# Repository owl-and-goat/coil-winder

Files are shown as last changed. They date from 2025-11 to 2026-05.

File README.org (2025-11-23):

#+title: coil winder

this repository contains the source for a mostly 3d-printed, gcode controlled,
wifi-connected cnc coil winder, including the [[https://github.com/owl-and-goat/coil-winder/tree/main/firmware][firmware]], a [[https://github.com/owl-and-goat/coil-winder/tree/main/client][client]] for controlling
it from a computer, a simple [[https://github.com/owl-and-goat/coil-winder/tree/main/slicer]["slicer" program]] for generating gcode to wind
various sorts of electromagnetic coils, and the [[https://github.com/owl-and-goat/coil-winder/tree/main/parts][STL files]] for the 3D-printed parts

the whole thing is driven off of a single [[https://www.raspberrypi.com/products/raspberry-pi-pico/][pi pico w]] microcontroller, with four
[[https://www.adafruit.com/product/6109][a4988 stepper driver]] boards for controlling the stepper motors.

coming soon: a longer writeup of how everything works, including instructions on
how to build one yourself if you want

* photos

here's how it looks in cad:

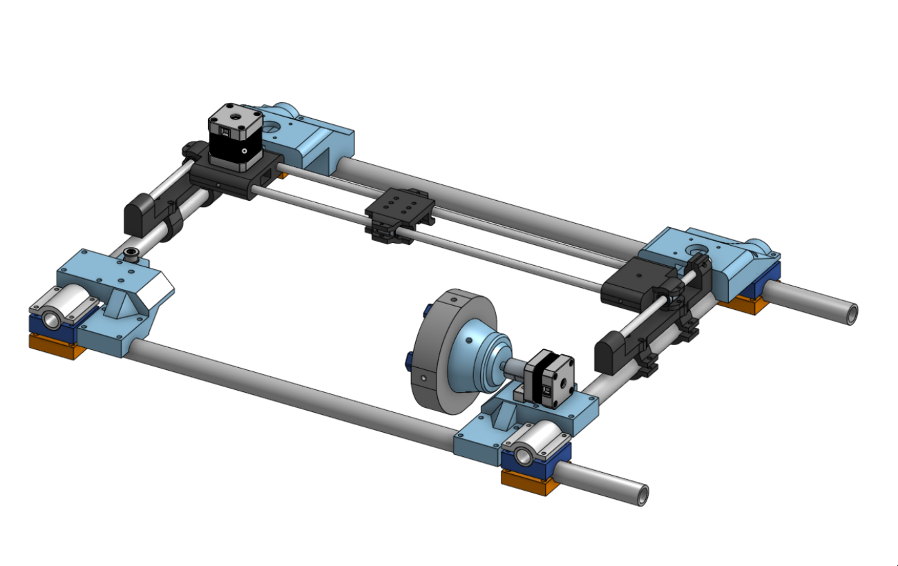
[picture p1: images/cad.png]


and here's how it looks in real life:

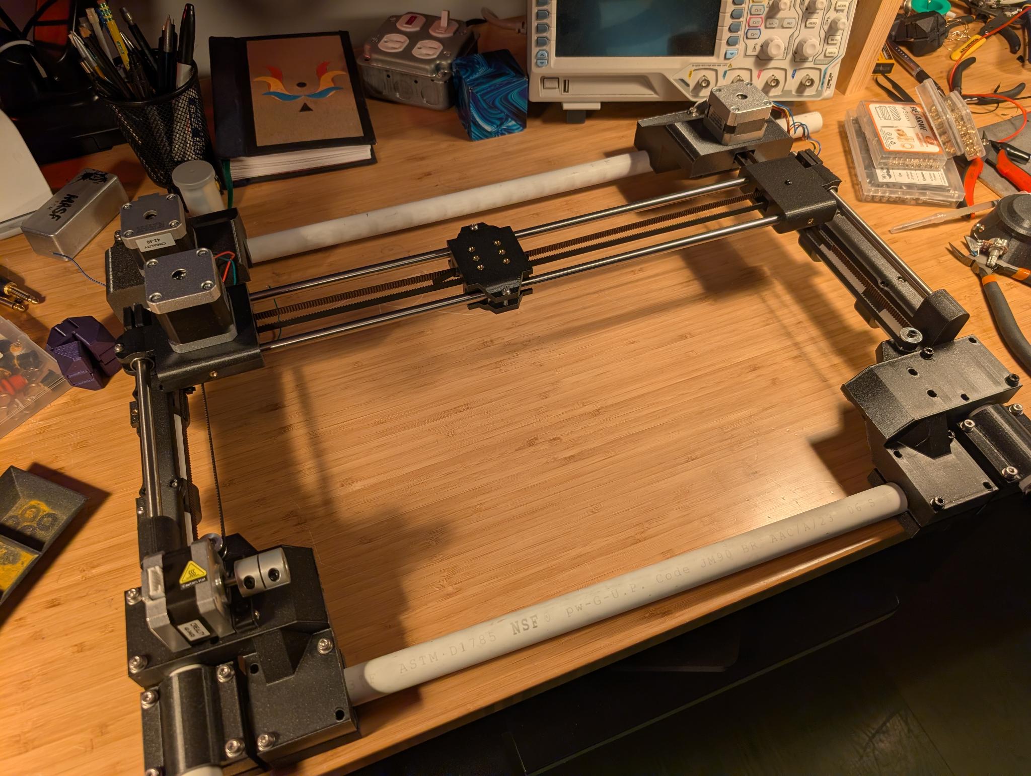
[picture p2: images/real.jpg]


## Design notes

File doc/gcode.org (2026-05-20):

#+TITLE: Supported GCode commands

We've been using https://reprap.org/wiki/G-code for inspiration.

+ *G0 X<x> Z<z> C<c> F<f>* - Rapid move
  All coordinates optional

  *F* is feedrate, in millimeters per second

+ *G1 X<x> Z<z> C<c> F<f>* - Linear move
  All coordinates optional

  *F* is feedrate, in millimeters per second

  G0 and G1 are synonyms for now

+ *G4 <dur>* - Dwell (sleep)

+ *G28 [F<speed>]* - Home

  *F* is optional feedrate, in millimeters per second. Defaults to 120

+ *M0* - Stop

+ *M17* - Enable all steppers

+ *M18* - Disable all steppers

+ *M112* - Force stop (resets processor)

+ *M114* - Get current position

  Prints current position to debug console

+ *M226* - Pause

  Pause until the "Resume" button is pressed

* Standard preamble

#+begin_src gcode
M0
M17
G28
#+end_src

* Standard postamble

#+begin_src gcode
M18
#+end_src

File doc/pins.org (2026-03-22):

#+title: Pins

* Axes

In order:
- *X* - diameter axis. two motors
- *Z* - axis parallel to the spindle. one motor
- *C* - spindle

** Pins

#+attr_org: :width 1000
[[file:./pico-2-r4-pinout.svg]]

all directions (left, right, ...) are given wrt. the pico in the above
orientation.

- sleep (all axes): pin 15

- *X*
  (controllers to the left of the pico, and the left zero limit input)
  - step: pin 4
  - dir: pin 5
  - zero limit: pin 2
- *Z*
  (controller to the lower right of the pico, and the right zero limit input)
  - step: pin 20
  - dir: pin 21
  - zero limit: pin 3
- *C*
  (controller to the upper right of the pico)
  - step: pin 16
  - dir: pin 17

positive is at the front right corner if the spindle is at the back right

** X-Axis Motor Sync

really just so we don't have to screw this up if we take this apart and
reassemble it.

- motor with colored wires: from left, red, green, yellow, blue (corresponding to
  2B, 2A, 1A, 1B)
- motor with ribbon: plug ribbon in in the same orientation as it comes out of
  the motor (with the non-shaft end of the motor up).

this should align everyone nicely.

** Z-Axis Wire Order

from the left: red, blue, black, green.

** C-Axis Wire Order

the most natural orientation if the ribbon is folded away from the motor: shaft
side facing up.

* Status indicators

- *LEDs*
  - amber: pin 7
  - green: pin 10
  - red: pin 13

* Resume / Confirm

- pin 22

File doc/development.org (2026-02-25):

#+title: Firmware development

* Flashing

To flash the firmware:

#+begin_src shell :dir ..
cd firmware && WIFI_NETWORK=network WIFI_PASSWORD=password cargo flash --release
#+end_src

* Accessing logs

#+begin_src shell :dir ..
cd firmware && probe-rs attach --chip rp2040 target/thumbv6m-none-eabi/release/coil-winder
#+end_src

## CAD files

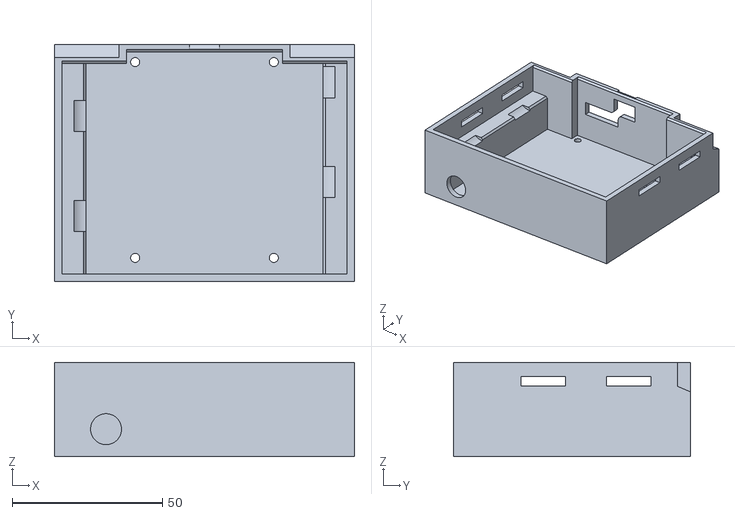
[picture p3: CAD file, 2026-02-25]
parts/circuit board enclosure - enclosure.stl
99.8 x 79.0 x 31.4

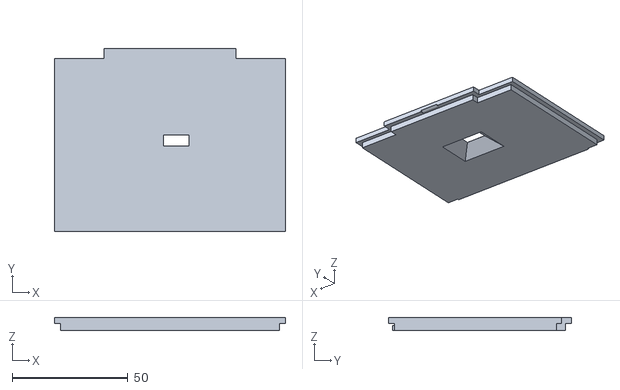
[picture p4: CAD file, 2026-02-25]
parts/circuit board enclosure - enclosure lid.stl
99.8 x 79.0 x 5.50

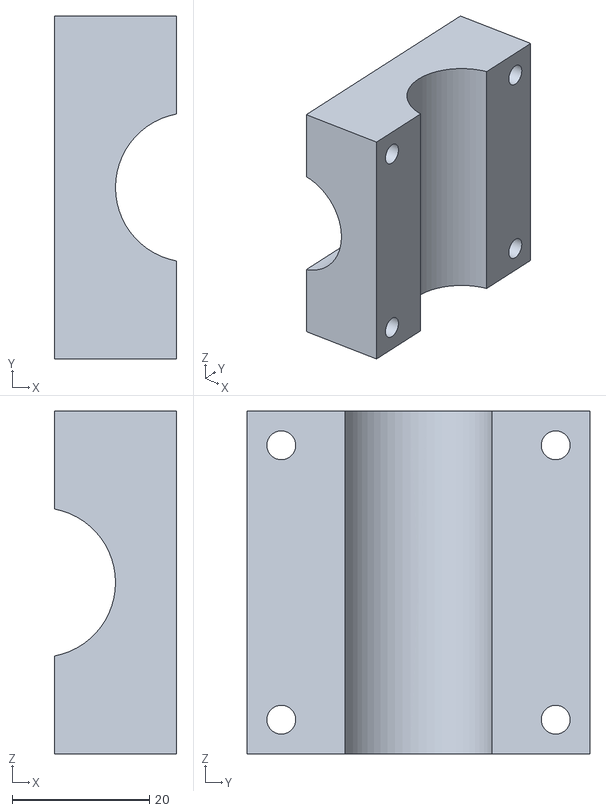
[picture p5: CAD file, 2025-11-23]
parts/coil winder - pvc 90deg middle.stl
17.8 x 50.0 x 50.0

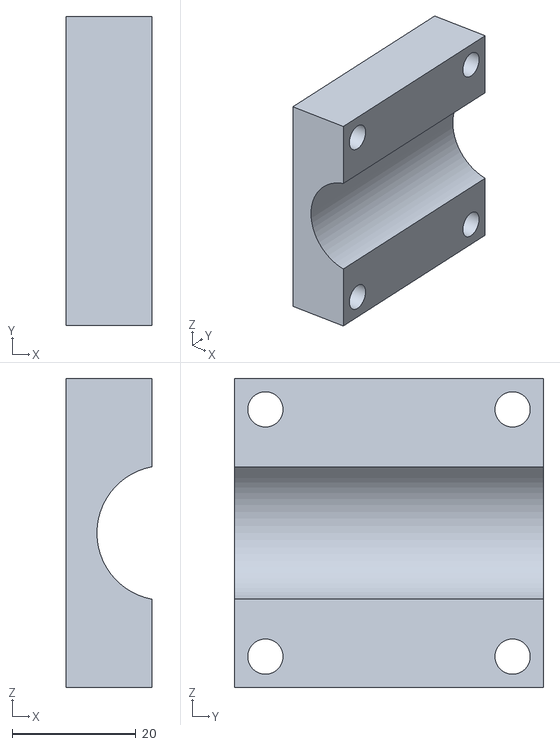
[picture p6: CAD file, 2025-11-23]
parts/coil winder - pvc 90deg top.stl
13.9 x 50.0 x 50.0

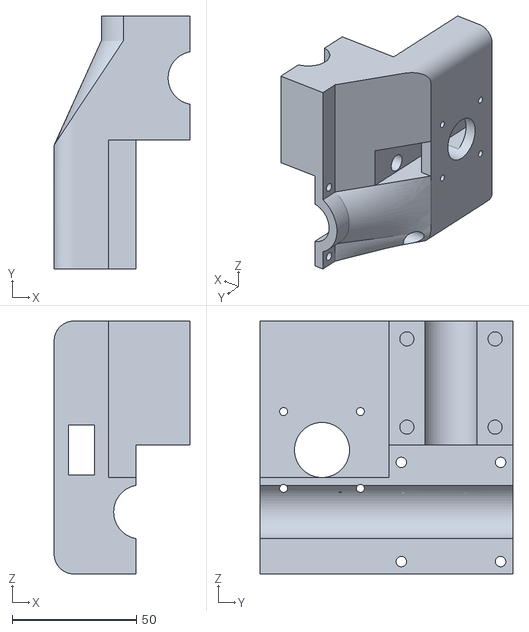
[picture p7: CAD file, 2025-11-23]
parts/coil winder - y axis motor housing.stl
54.7 x 102.0 x 102.0

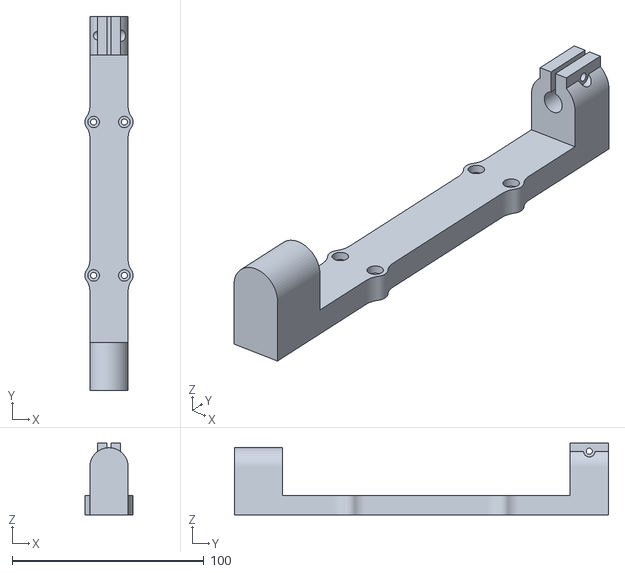
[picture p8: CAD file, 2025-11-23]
parts/coil winder - x axis bracket.stl
25.2 x 195.0 x 37.4

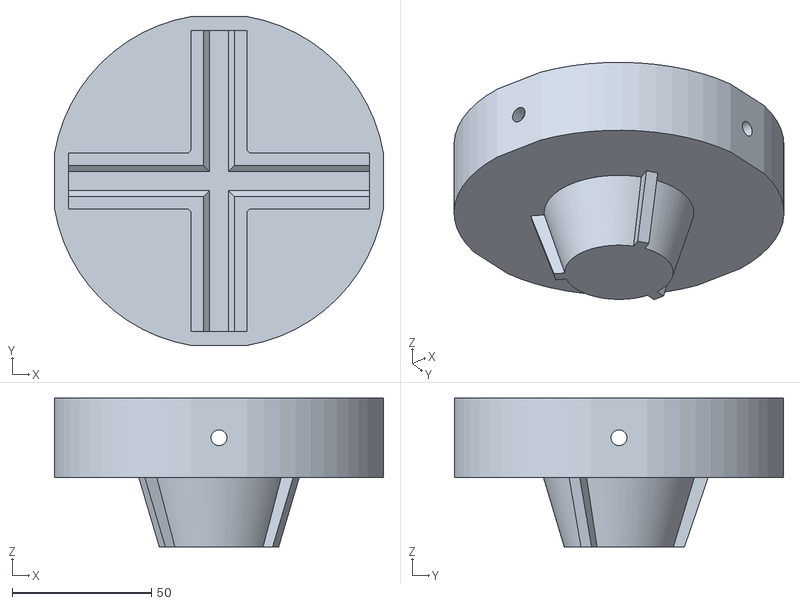
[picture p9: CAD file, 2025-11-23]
parts/coil winder - chuck.stl
118.3 x 118.3 x 53.5

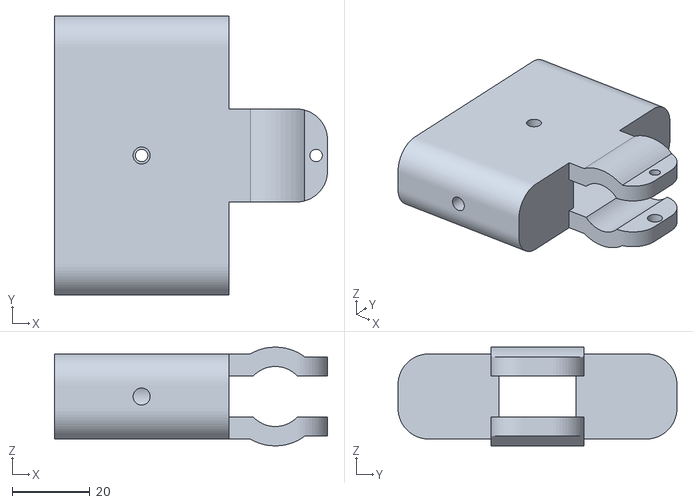
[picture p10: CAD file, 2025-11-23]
parts/coil winder - z idler bracket.stl
70.5 x 72.0 x 25.5

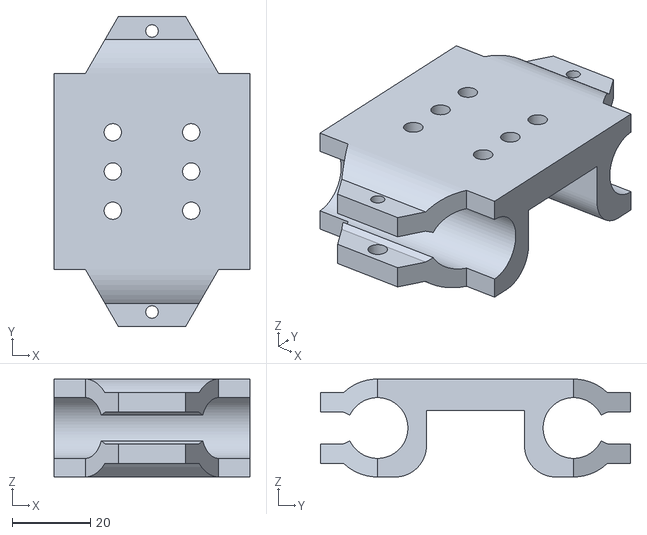
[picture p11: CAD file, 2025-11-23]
parts/coil winder - carriage.stl
50.0 x 79.1 x 25.0

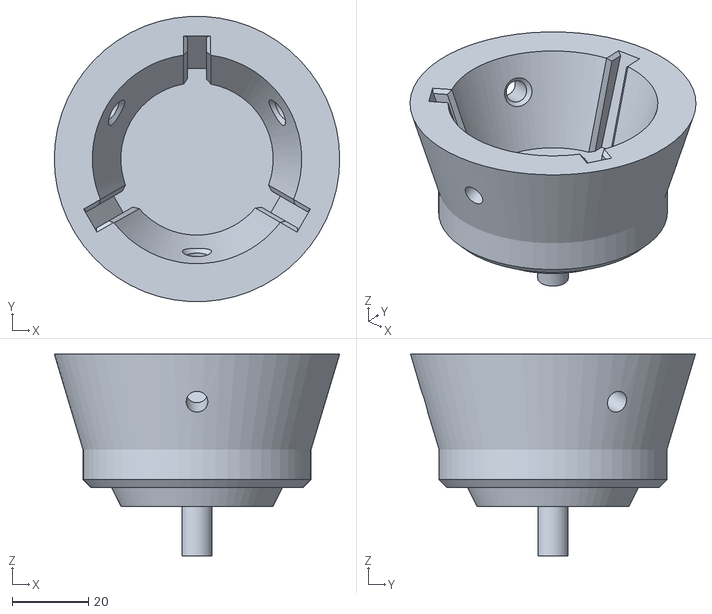
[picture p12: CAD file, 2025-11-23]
parts/coil winder - collet.stl
75.0 x 74.9 x 53.0

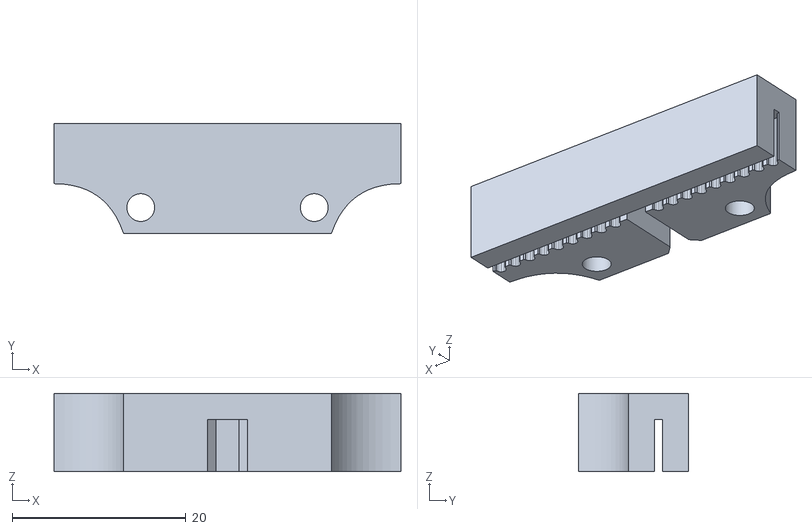
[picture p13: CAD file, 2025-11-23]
parts/coil winder - belt tensioner.stl
40.0 x 12.7 x 9.00

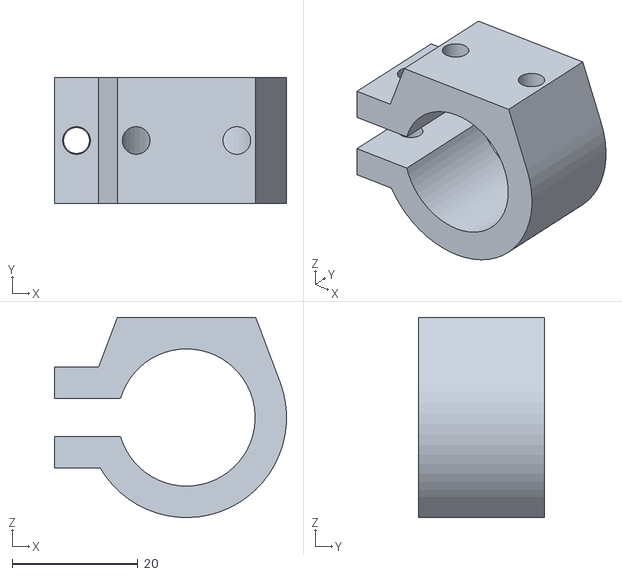
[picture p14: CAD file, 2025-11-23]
parts/coil winder - pvc x axis mount.stl
36.9 x 20.0 x 31.8

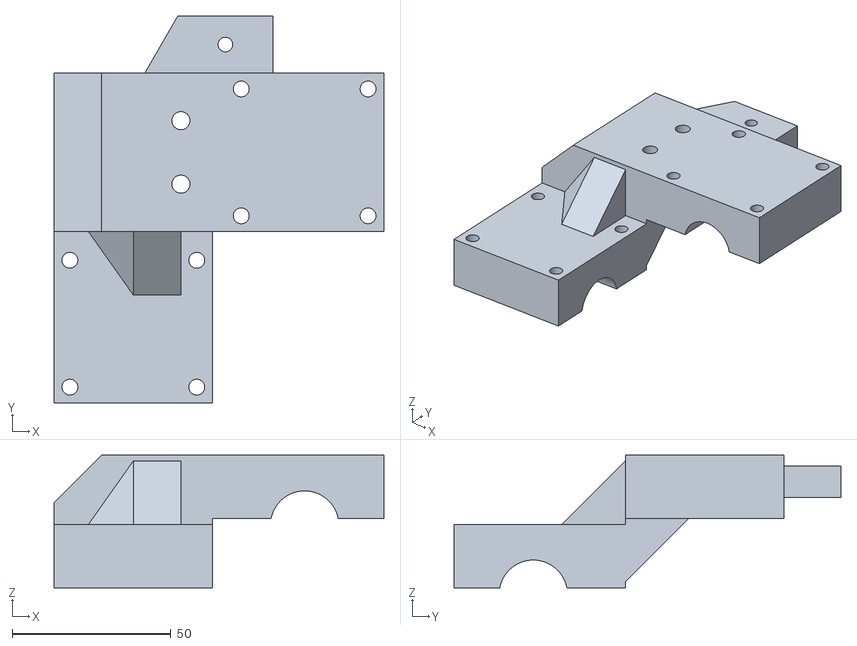
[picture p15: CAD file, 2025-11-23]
parts/coil winder - spindle bracket.stl
104.0 x 122.0 x 41.8

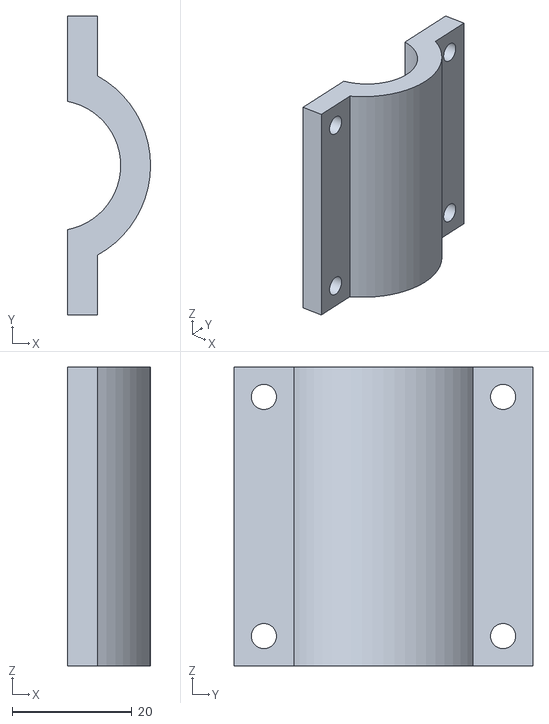
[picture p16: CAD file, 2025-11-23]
parts/coil winder - pvc 90deg bottom.stl
13.9 x 50.0 x 50.0

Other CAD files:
parts/coil winder - z motor bracket.stl
parts/coil winder - spindle bracket (mirrored).stl
parts/coil winder - jaw.stl
parts/coil winder - y axis motor housing, mirr.stl

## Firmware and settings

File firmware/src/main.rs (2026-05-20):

#![no_std]
#![no_main]
#![feature(impl_trait_in_assoc_type)]

use core::{net::Ipv4Addr, ptr::addr_of_mut};

use cyw43::JoinOptions;
use cyw43_pio::{DEFAULT_CLOCK_DIVIDER, PioSpi};
use defmt::*;
use embassy_executor::{Executor, Spawner};
use embassy_futures::select::Either;
use embassy_net::StackResources;
use embassy_rp::{
    Peri, bind_interrupts,
    clocks::RoscRng,
    gpio::{Input, Level, Output, Pull},
    multicore::Stack,
    peripherals::{DMA_CH0, PIN_0, PIO0},
    pio::{InterruptHandler, Pio},
    watchdog::Watchdog,
};
use embassy_sync::{blocking_mutex::raw::CriticalSectionRawMutex, channel, signal};
use embassy_time::{Duration, with_timeout};
use static_cell::StaticCell;

use crate::{
    cancellation::{Cancellation, Cancelled},
    motion::ICoord,
    status_leds::{Behavior, BlinkSpeed, Status},
};

use {defmt_rtt as _, panic_probe as _};

#[macro_use]
pub(crate) mod util;
mod cancellation;
mod driver;
mod mdns;
mod motion;
mod server;
mod status_leds;

pub(crate) const WIFI_NETWORK: Option<&str> = option_env!("WIFI_NETWORK");
pub(crate) const WIFI_PASSWORD: Option<&str> = option_env!("WIFI_PASSWORD");
pub(crate) const PORT: u16 = 1234;
pub(crate) const MDNS_HOSTNAME: &str = "coil-winder";
pub(crate) const AXES: usize = 4;
pub(crate) const AXIS_LABELS: [char; AXES] = ['X', 'Z', 'C', 'F'];
pub(crate) const CANCEL_WATCHERS: usize = 2;
pub const COMMAND_BUFFER_SIZE: usize = 32;

#[derive(Debug, Clone, Copy, PartialEq, Eq, Format)]
pub struct CommandId(pub u32);

#[derive(Debug, Clone, Copy, PartialEq, Eq, Format)]
pub enum MotionStatusMsg {
    CommandFinished(CommandId),
}

bind_interrupts!(struct Irqs {
    PIO0_IRQ_0 => InterruptHandler<PIO0>;
});

#[embassy_executor::task]
async fn cyw43_task(
    runner: cyw43::Runner<'static, Output<'static>, PioSpi<'static, PIO0, 0, DMA_CH0>>,
) -> ! {
    runner.run().await
}

#[embassy_executor::task]
async fn net_task(mut runner: embassy_net::Runner<'static, cyw43::NetDriver<'static>>) -> ! {
    runner.run().await
}

#[embassy_executor::task]
async fn server_task(server: server::Server) -> ! {
    server.run().await
}

#[embassy_executor::task]
async fn motion_task(
    motion: motion::State,
    driver: driver::Control,
    command_rx: channel::Receiver<
        'static,
        CriticalSectionRawMutex,
        (CommandId, gcode::Command<AXES>),
        COMMAND_BUFFER_SIZE,
    >,
    last_completed: &'static signal::Signal<CriticalSectionRawMutex, CommandId>,
    cancel_tx: cancellation::Sender<'static, CriticalSectionRawMutex, CANCEL_WATCHERS>,
) -> ! {
    motion
        .run(driver, command_rx, last_completed, cancel_tx)
        .await;
}

#[embassy_executor::task]
async fn driver_task(
    mut driver: driver::Driver<'static, PIO0, 1, 2, 3>,
    mut cancel_rx: cancellation::Receiver<'static, CriticalSectionRawMutex, CANCEL_WATCHERS>,
) -> ! {
    loop {
        let Err(Cancelled(command_id)) = cancel_rx.try_(driver.run()).await;
        info!("canceling driver run");
        driver.stop(command_id).await;
    }
}

#[embassy_executor::task]
async fn command_completion_task(
    command_completion: driver::CommandCompletion<'static, PIO0, 1, 2, 3>,
    status_tx: channel::Sender<
        'static,
        CriticalSectionRawMutex,
        MotionStatusMsg,
        COMMAND_BUFFER_SIZE,
    >,
    last_completed: &'static signal::Signal<CriticalSectionRawMutex, CommandId>,
    cancel_rx: cancellation::Receiver<'static, CriticalSectionRawMutex, CANCEL_WATCHERS>,
) -> ! {
    command_completion
        .run(status_tx, last_completed, cancel_rx)
        .await
}

#[embassy_executor::task]
async fn status_leds_task(runner: status_leds::Runner<'static>) -> ! {
    runner.run().await
}

#[embassy_executor::task]
async fn mdns_task(
    stack: embassy_net::Stack<'static>,
    hostname: &'static str,
    ip: Ipv4Addr,
    rng: RoscRng,
) -> ! {
    mdns::run(stack, hostname, ip, rng).await
}

fn status_behavior(status: Status) -> status_leds::PerColor<Behavior> {
    match status {
        Status::Initializing => status_leds::PerColor {
            amber: Behavior::On,
            ..Default::default()
        },
        Status::WifiConnecting => status_leds::PerColor {
            amber: Behavior::Blink(BlinkSpeed::Fast),
            ..Default::default()
        },
        Status::WaitingForDhcp => status_leds::PerColor {
            amber: Behavior::Blink(BlinkSpeed::Slow),
            ..Default::default()
        },
        Status::Ready => status_leds::PerColor {
            green: Behavior::On,
            ..Default::default()
        },
        Status::Paused => status_leds::PerColor {
            green: Behavior::Blink(BlinkSpeed::Fast),
            ..Default::default()
        },
        Status::WifiError => status_leds::PerColor {
            red: Behavior::On,
            ..Default::default()
        },
        Status::ExecutingCommand => status_leds::PerColor {
            green: Behavior::On,
            amber: Behavior::Blink(BlinkSpeed::Slow),
            ..Default::default()
        },
        Status::XHomingFailed => status_leds::PerColor {
            red: Behavior::Blink(BlinkSpeed::Fast),
            amber: Behavior::On,
            ..Default::default()
        },
        Status::ZHomingFailed => status_leds::PerColor {
            red: Behavior::On,
            amber: Behavior::Blink(BlinkSpeed::Fast),
            ..Default::default()
        },
        Status::BothHomingFailed => status_leds::PerColor {
            red: Behavior::Blink(BlinkSpeed::Fast),
            amber: Behavior::Blink(BlinkSpeed::Fast),
            ..Default::default()
        },
        Status::BadCommand => status_leds::PerColor {
            green: Behavior::On,
            red: Behavior::Blink(BlinkSpeed::Slow),
            ..Default::default()
        },
    }
}

#[embassy_executor::task]
async fn core0(
    pwr: Output<'static>,
    spi: PioSpi<'static, PIO0, 0, DMA_CH0>,
    spawner: Spawner,
    status_leds_runner: status_leds::Runner<'static>,
    command_tx: channel::Sender<
        'static,
        CriticalSectionRawMutex,
        (CommandId, gcode::Command<AXES>),
        COMMAND_BUFFER_SIZE,
    >,
    status_rx: channel::Receiver<
        'static,
        CriticalSectionRawMutex,
        MotionStatusMsg,
        COMMAND_BUFFER_SIZE,
    >,
    watchdog: Watchdog,
) -> ! {
    let status_leds = status_leds_runner.control();
    spawner.must_spawn(status_leds_task(status_leds_runner));
    status_leds.set_status(Status::Initializing);

    let fw = include_bytes!("../cyw43-firmware/43439A0.bin");
    let clm = include_bytes!("../cyw43-firmware/43439A0_clm.bin");

    let state = make_static!(cyw43::State, cyw43::State::new());
    let (net_device, mut control, runner) = cyw43::new(state, pwr, spi, fw).await;
    spawner.must_spawn(cyw43_task(runner));

    control.init(clm).await;

    control
        .set_power_management(cyw43::PowerManagementMode::Performance)
        .await;

    // Init network stack with DHCP
    let (stack, runner) = embassy_net::new(
        net_device,
        embassy_net::Config::dhcpv4(Default::default()),
        make_static!(StackResources<4>, StackResources::new()),
        RoscRng.next_u64(),
    );
    spawner.must_spawn(net_task(runner));

    status_leds.set_status(Status::WifiConnecting);
    while let Err(err) = match with_timeout(
        Duration::from_secs(5),
        control.join(
            WIFI_NETWORK.unwrap_or(""),
            JoinOptions::new(WIFI_PASSWORD.unwrap_or("").as_bytes()),
        ),
    )
    .await
    {
        Ok(Ok(())) => Ok(()),
        Err(timeout) => Err(Either::First(timeout)),
        Ok(Err(join_error)) => Err(Either::Second(join_error)),
    } {
        match err {
            Either::First(timeout) => error!("Join timed out, retrying ({})", timeout),
            Either::Second(err) => {
                status_leds.set_status(Status::WifiError);
                info!("join failed with status={}", err.status)
            }
        }
    }
    // Wait for DHCP to assign an IP
    info!("Waiting for DHCP...");
    status_leds.set_status(Status::WaitingForDhcp);
    stack.wait_config_up().await;
    let our_ip = stack
        .config_v4()
        .map(|c| c.address.address())
        .unwrap_or(Ipv4Addr::UNSPECIFIED);
    info!("DHCP assigned IP: {}", our_ip);
    status_leds.set_status(Status::Ready);

    // Add mDNS multicast MAC address to cyw43 hardware filter
    // IPv4 multicast 224.0.0.251 -> MAC 01:00:5e:00:00:fb
    const MDNS_MULTICAST_MAC: [u8; 6] = [0x01, 0x00, 0x5e, 0x00, 0x00, 0xfb];
    match control.add_multicast_address(MDNS_MULTICAST_MAC).await {
        Ok(_) => info!("Added mDNS multicast MAC filter"),
        Err(_) => error!("Failed to add mDNS multicast MAC"),
    }

    // Start mDNS responder
    spawner.must_spawn(mdns_task(stack, MDNS_HOSTNAME, our_ip, RoscRng));

    server::Server {
        stack,
        command_tx,
        status_rx,
        command_id_gen: 0,
        watchdog,
    }
    .run()
    .await
}

static mut CORE1_STACK: Stack<4096> = Stack::new();
static EXECUTOR0: StaticCell<Executor> = StaticCell::new();
static EXECUTOR1: StaticCell<Executor> = StaticCell::new();

#[cortex_m_rt::entry]
fn main() -> ! {
    let p = embassy_rp::init(Default::default());

    let status = make_static!(status_leds::Control, status_leds::Control::new());
    let status_leds = status_leds::Runner::new(
        status,
        status_leds::PerColor {
            amber: Output::new(p.PIN_7, Level::Low),
            green: Output::new(p.PIN_10, Level::Low),
            red: Output::new(p.PIN_13, Level::Low),
        },
        status_behavior,
    );

    let status_leds_control = status_leds.control();

    let pwr = Output::new(p.PIN_23, Level::Low);
    let cs = Output::new(p.PIN_25, Level::High);
    let mut pio = Pio::new(p.PIO0, Irqs);
    let spi = PioSpi::new(
        &mut pio.common,
        pio.sm0,
        DEFAULT_CLOCK_DIVIDER,
        pio.irq0,
        cs,
        p.PIN_24,
        p.PIN_29,
        p.DMA_CH0,
    );

    static COMMAND_CHANNEL: StaticCell<
        channel::Channel<
            CriticalSectionRawMutex,
            (CommandId, gcode::Command<AXES>),
            COMMAND_BUFFER_SIZE,
        >,
    > = StaticCell::new();
    let command_channel: &'static mut _ = COMMAND_CHANNEL.init(channel::Channel::new());
    let command_tx = command_channel.sender();
    let command_rx = command_channel.receiver();

    static STATUS_CHANNEL: StaticCell<
        channel::Channel<CriticalSectionRawMutex, MotionStatusMsg, COMMAND_BUFFER_SIZE>,
    > = StaticCell::new();
    let status_channel: &'static _ = STATUS_CHANNEL.init(channel::Channel::new());
    let status_tx = status_channel.sender();
    let status_rx = status_channel.receiver();

    static LAST_COMPLETED: StaticCell<signal::Signal<CriticalSectionRawMutex, CommandId>> =
        StaticCell::new();
    let last_completed: &'static _ = LAST_COMPLETED.init(signal::Signal::new());

    static CANCELLATION: StaticCell<Cancellation<CriticalSectionRawMutex, CANCEL_WATCHERS>> =
        StaticCell::new();
    let cancellation: &'static _ = CANCELLATION.init(Cancellation::new());
    let cancel_tx = cancellation.sender();
    let cancel_driver = cancellation
        .receiver()
        .expect("cancellation channel should have at least 1 receiver available");
    let cancel_completion = cancellation
        .receiver()
        .expect("cancellation channel should have at least 1 receiver available");

    let watchdog = Watchdog::new(p.WATCHDOG);

    embassy_rp::multicore::spawn_core1(
        p.CORE1,
        unsafe { &mut *addr_of_mut!(CORE1_STACK) },
        move || {
            let executor1 = EXECUTOR1.init(Executor::new());
            executor1.run(|spawner| {
                let prgs = driver::Programs::new(&mut pio.common);
                let driver_channel = make_static!(driver::Channel, driver::Channel::new());
                let (command_completion, driver_control, driver) = driver::Driver::new(
                    pio.common,
                    /* sleep_pin = */ p.PIN_15,
                    driver::config::Axes {
                        x_axis: driver::config::Axis {
                            step: p.PIN_4,
                            dir: p.PIN_5,
                            zero_limit: Some(p.PIN_2),
                            irq: Some(pio.irq1),
                            sm: pio.sm1,
                        },
                        z_axis: driver::config::Axis {
                            step: p.PIN_20,
                            dir: p.PIN_21,
                            zero_limit: Some(p.PIN_3),
                            irq: Some(pio.irq2),
                            sm: pio.sm2,
                        },
                        c_axis: driver::config::Axis {
                            step: p.PIN_16,
                            dir: p.PIN_17,
                            zero_limit: None::</* can put anything here, lol */ Peri<PIN_0>>,
                            irq: Some(pio.irq3),
                            sm: pio.sm3,
                        },
                    },
                    prgs,
                    driver_channel,
                );

                spawner.must_spawn(driver_task(driver, cancel_driver));
                spawner.must_spawn(command_completion_task(
                    command_completion,
                    status_tx,
                    last_completed,
                    cancel_completion,
                ));

                spawner.must_spawn(motion_task(
                    motion::State::new(
                        [
                            /* X */
                            motion::Axis {
                                microns_per_step: ICoord::from_num(12).into(),
                                degrees_per_step: (ICoord::lit("1.8") / ICoord::from_num(16))
                                    .into(),
                                unit: motion::AxisUnit::Millimeters,
                                length: ICoord::from_num(140),
                            },
                            /* Z */
                            motion::Axis {
                                microns_per_step: (ICoord::from_num(6)).into(),
                                degrees_per_step: (ICoord::lit("0.9") / ICoord::from_num(16))
                                    .into(),
                                unit: motion::AxisUnit::Millimeters,
                                length: ICoord::from_num(400),
                            },
                            /* C */
                            motion::Axis {
                                microns_per_step: ICoord::from_num(12).into(),
                                degrees_per_step: (ICoord::lit("1.8") / ICoord::from_num(16))
                                    .into(),
                                unit: motion::AxisUnit::Rotations,
                                length: ICoord::from_num(0),
                            },
                        ],
                        status_leds_control,
                        Input::new(p.PIN_22, Pull::Up),
                    ),
                    driver_control,
                    command_rx,
                    last_completed,
                    cancel_tx,
                ))
            })
        },
    );

    let executor0 = EXECUTOR0.init(Executor::new());
    executor0.run(|spawner| {
        spawner.must_spawn(core0(
            pwr,
            spi,
            spawner,
            status_leds,
            command_tx,
            status_rx,
            watchdog,
        ))
    })
}

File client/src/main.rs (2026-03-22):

use std::{
    collections::HashMap,
    fmt::{self, Debug, Display},
    io::{BufRead, ErrorKind, Read},
    net::SocketAddr,
    sync::{
        Arc,
        atomic::{AtomicBool, Ordering},
    },
};

use clap::Parser;
use clio::Input;
use eyre::{Result, bail, eyre};
use indicatif::{MultiProgress, ProgressBar, ProgressStyle};
use lexpr::Value;
use rustyline_async::ReadlineEvent;
use tokio::{
    io::{self, AsyncBufReadExt, AsyncWriteExt, BufReader},
    net::{TcpStream, ToSocketAddrs, tcp},
    select, signal,
    sync::{Mutex, mpsc},
    task::JoinHandle,
};
use tracing::{Level, debug, info, instrument, warn};

const AXES: usize = 4;
const AXIS_LABELS: [char; AXES] = ['X', 'Z', 'C', 'F'];

#[derive(clap::Subcommand, Debug)]
enum Command {
    /// Interactive REPL for sending gcode commands
    Repl,

    /// Send a single Gcode command from the command line
    Oneshot {
        /// Command to send
        #[clap(long, short)]
        command: String,
    },

    /// Run a gcode program
    Run {
        /// Path to gcode program to run
        #[clap(value_parser)]
        program: Input,

        /// Skip verification that the program parses before running
        #[clap(long)]
        no_verify: bool,
    },
}

#[derive(clap::Parser, Debug)]
#[command(version)]
struct Args {
    #[clap(long, short, default_value = "coil-winder.local:1234")]
    addr: String,

    #[clap(subcommand)]
    command: Command,
}

fn read_commands(input: impl Read, verify: bool) -> Result<Vec<String>> {
    let reader = std::io::BufReader::new(input);
    let mut res = Vec::new();
    if !verify {
        for line in reader.lines() {
            res.push(line?);
        }
    } else {
        for (i, line) in reader.lines().enumerate() {
            let line = line?;
            let line = line.trim();
            if line.starts_with('(') {
                if !line.ends_with(')') {
                    bail!("line {i}: Mismatched parenthesis in comment");
                }
                continue;
            }
            let line = match line.rsplit_once(';') {
                Some((line, _comment)) => line,
                None => line,
            };
            let mut line = line.to_owned();
            if !line.ends_with('\n') {
                line.push('\n');
            }
            match gcode::parse_single_command(AXIS_LABELS, line.as_bytes()) {
                Ok(_) => {}
                Err(_) => bail!("line {i}: Invalid gcode command: \"{}\"", line.trim()),
            };
            res.push(line);
        }
    }

    Ok(res)
}

#[derive(Debug, Clone, Copy, PartialEq, Eq, Hash)]
pub struct CommandId(u32);

impl Display for CommandId {
    fn fmt(&self, f: &mut fmt::Formatter<'_>) -> fmt::Result {
        write!(f, "{}", self.0)
    }
}

#[derive(Debug, Clone, Copy, PartialEq, Eq)]
pub struct Ack(Option<CommandId>);

#[derive(Debug, Clone, Copy, PartialEq, Eq)]
pub struct Done(CommandId);

#[derive(Debug, Clone, Copy, PartialEq, Eq)]
pub enum Response {
    Ack(Ack),
    Done(Done),
}

impl Response {
    fn from_sexp(value: lexpr::Value) -> Result<Self, lexpr::Value> {
        match value.get(0) {
            Some(Value::Symbol(s)) if s.as_ref() == "ack" => match value.get(1) {
                None => Ok(Self::Ack(Ack(None))),
                Some(id) => {
                    match id
                        .as_number()
                        .and_then(|v| v.as_u64())
                        .and_then(|v| u32::try_from(v).ok())
                    {
                        Some(id) => Ok(Self::Ack(Ack(Some(CommandId(id as _))))),
                        None => Err(value),
                    }
                }
            },
            Some(Value::Symbol(s)) if s.as_ref() == "done" => {
                match value
                    .get(1)
                    .and_then(|v| v.as_number())
                    .and_then(|v| v.as_u64())
                    .and_then(|v| u32::try_from(v).ok())
                {
                    Some(id) => Ok(Self::Done(Done(CommandId(id as _)))),
                    None => Err(value),
                }
            }
            None => {
                if value.as_str() == Some("ack") {
                    Ok(Self::Ack(Ack(None)))
                } else {
                    Err(value)
                }
            }
            _ => Err(value),
        }
    }
}

#[cfg(test)]
mod response_tests {
    use super::*;

    fn resp_from_sexp(sexp: &str) -> Response {
        let sexp = lexpr::from_str(sexp).unwrap();
        Response::from_sexp(sexp).unwrap()
    }

    #[test]
    fn ack() {
        assert_eq!(resp_from_sexp("(ack)"), Response::Ack(Ack(None)));
    }

    #[test]
    fn done() {
        assert_eq!(
            resp_from_sexp("(done 8)"),
            Response::Done(Done(CommandId(8)))
        );
    }
}

pub struct Client {
    addr: SocketAddr,
    ack_rx: mpsc::Receiver<Ack>,
    ack_tx: mpsc::Sender<Ack>,
    done_tx: mpsc::UnboundedSender<Done>,
    writer: tcp::OwnedWriteHalf,
    reader: JoinHandle<()>,
}
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

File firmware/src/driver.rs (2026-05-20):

//! Ref: https://www.allegromicro.com/-/media/files/datasheets/a4988-datasheet.pdf

use defmt::{Format, debug, info};
use embassy_futures::join::{join, join3};
use embassy_rp::{
    Peri,
    gpio::{self, Level, Pull},
    pio::{self, PioPin},
    pio_programs::clock_divider::calculate_pio_clock_divider,
};
use embassy_sync::{
    blocking_mutex::raw::{CriticalSectionRawMutex, NoopRawMutex},
    channel, signal,
};
use embassy_time::Instant;
use fixed::types::extra::U8;

use crate::{
    CANCEL_WATCHERS, COMMAND_BUFFER_SIZE, CommandId, MotionStatusMsg,
    cancellation::{self, Cancelled},
};

const PIO_TARGET_HZ: u32 =
    // 2 μs per cycle
    500_000;

#[derive(Debug, Format, Clone, Copy, PartialEq, Eq, PartialOrd, Ord)]
pub struct StepsPerSecond(pub u32);

#[derive(Debug, Clone, Copy, PartialEq, Eq, PartialOrd, Ord)]
pub enum Direction {
    Forwards,
    Backwards,
}

impl From<i32> for Direction {
    fn from(value: i32) -> Self {
        if value > 0 {
            Self::Forwards
        } else {
            Self::Backwards
        }
    }
}

/// The number of instructions per loop of the pio program. Gives a fixed overhead to the incoming
/// "sleeps per cycle" count
const LOOP_OVERHEAD: u32 = 4;

impl StepsPerSecond {
    fn to_sleep_cyles_per_step(self) -> u32 {
        // TODO(aspen): division error?? probably doesn't matter?
        if self.0 == 0 {
            // This doesn't matter (we get 0 speed if we aren't moving), so we return Big Safe
            // Number
            return PIO_TARGET_HZ;
        }
        (PIO_TARGET_HZ / self.0).saturating_sub(LOOP_OVERHEAD)
    }
}

pub struct Programs<'a, T: pio::Instance> {
    home: pio::LoadedProgram<'a, T>,
    move_: pio::LoadedProgram<'a, T>,
}

impl<'a, T: pio::Instance> Programs<'a, T> {
    /// Load the program into the given pio
    pub fn new(common: &mut pio::Common<'a, T>) -> Self {
        let home = common.load_program(&::pio::pio_file!("src/home.s").program);
        let move_ = common.load_program(&::pio::pio_file!("src/move.s").program);
        Self { home, move_ }
    }
}

pub mod config {
    use super::*;
    use embassy_rp::pio::PioPin;

    pub struct Axis<'d, T: pio::Instance, D: PioPin, S: PioPin, ZL: PioPin, const SM: usize> {
        /// Direction pin
        pub dir: Peri<'d, D>,
        /// Step pin
        pub step: Peri<'d, S>,
        /// Zero limit switch input pin
        pub zero_limit: Option<Peri<'d, ZL>>,
        pub irq: Option<pio::Irq<'d, T, SM>>,
        pub sm: pio::StateMachine<'d, T, SM>,
    }

    pub struct Axes<
        'd,
        T: pio::Instance,
        XD: PioPin,
        XS: PioPin,
        XZL: PioPin,
        const XSM: usize,
        ZD: PioPin,
        ZS: PioPin,
        ZZL: PioPin,
        const ZSM: usize,
        CD: PioPin,
        CS: PioPin,
        CZL: PioPin,
        const CSM: usize,
    > {
        pub x_axis: Axis<'d, T, XD, XS, XZL, XSM>,
        pub z_axis: Axis<'d, T, ZD, ZS, ZZL, ZSM>,
        pub c_axis: Axis<'d, T, CD, CS, CZL, CSM>,
    }
}

struct Axis<'d, T: pio::Instance, const SM: usize> {
    sm: pio::StateMachine<'d, T, SM>,
    // irq: pio::Irq<'d, T, SM>,
    dir_pin: pio::Pin<'d, T>,
    step_pin: pio::Pin<'d, T>,
    zero_limit_pin: Option<pio::Pin<'d, T>>,
}

impl<'d, T: pio::Instance, const SM: usize> Axis<'d, T, SM> {
    pub fn new(
        pio: &mut pio::Common<'d, T>,
        axis: config::Axis<'d, T, impl PioPin, impl PioPin, impl PioPin, SM>,
    ) -> Self {
        let config::Axis {
            mut sm,
            step,
            zero_limit,
            dir,
            irq: _,
        } = axis;

        let dir_pin = pio.make_pio_pin(dir);
        let step_pin = pio.make_pio_pin(step);

        sm.set_pin_dirs(pio::Direction::Out, &[&step_pin, &dir_pin]);

        let zero_limit_pin = zero_limit.map(|zero_limit| {
            let mut zero_limit_pin = pio.make_pio_pin(zero_limit);
            zero_limit_pin.set_pull(Pull::Up);
            zero_limit_pin.set_schmitt(true);
            sm.set_pin_dirs(pio::Direction::In, &[&zero_limit_pin]);
            zero_limit_pin
        });

        sm.set_enable(false);

        Self {
            sm,
            dir_pin,
            step_pin,
            zero_limit_pin,
        }
    }

    pub fn configure(
        &mut self,
        clock_divider: fixed::FixedU32<U8>,
        program: &pio::LoadedProgram<'d, T>,
    ) {
        let mut cfg = pio::Config::default();
        cfg.set_set_pins(&[&self.step_pin]);
        cfg.set_out_pins(&[&self.dir_pin]);

        if let Some(zero_limit_pin) = &self.zero_limit_pin {
            cfg.set_jmp_pin(zero_limit_pin);
        }

        cfg.clock_divider = clock_divider;
        cfg.use_program(program, &[&self.step_pin]);
        self.sm.set_config(&cfg);
    }

    pub(self) async fn push_speed(&mut self, speed: StepsPerSecond, direction: Direction) {
        let speed = speed.to_sleep_cyles_per_step();
        // steps.s expects the direction to be the least significant bit of speed - if direction is
        // negative, pin is low, if positive pin is high
        let speed_and_dir = (speed << 1)
            | (match direction {
                Direction::Forwards => 1u32,
                Direction::Backwards => 0u32,
            });
        self.sm.tx().wait_push(speed_and_dir).await;
    }
}

#[derive(Debug, Clone, Copy, PartialEq, Eq)]
enum ConfiguredProgram {
    Home,
    Move,
}

#[derive(Clone, Copy)]
pub struct HomeError {
    pub x_failed: bool,
    pub z_failed: bool,
}

#[derive(Debug, Clone, Copy)]
pub enum Command {
    /// XXX: used if we want to acknowledge that we finished a thing, but not
    /// actually do a thing
    ReportDone,
    Move {
        steps: [i32; 3],
        speeds: [StepsPerSecond; 3],
    },
    SetSleep(bool),
    Home {
        speeds: [(u32, StepsPerSecond); 2],
    },
}

pub const BUFFER_SIZE: usize = 8;

pub struct Channel {
    command: channel::Channel<NoopRawMutex, (CommandId, Command), BUFFER_SIZE>,
    command_started: channel::Channel<NoopRawMutex, CommandStarted, COMMAND_BUFFER_SIZE>,
    home_done: channel::Channel<NoopRawMutex, (), 1>,
    home_result: channel::Channel<NoopRawMutex, Result<(), HomeError>, 1>,
}

impl Channel {
    pub fn new() -> Self {
        Self {
            command: channel::Channel::new(),
            home_done: channel::Channel::new(),
            home_result: channel::Channel::new(),
            command_started: channel::Channel::new(),
        }
    }
}

pub struct Control {
    tx: channel::Sender<'static, NoopRawMutex, (CommandId, Command), BUFFER_SIZE>,
    home_rx: channel::Receiver<'static, NoopRawMutex, Result<(), HomeError>, 1>,
}
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

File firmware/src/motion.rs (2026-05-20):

use az::SaturatingCast;
use defmt::{Display2Format, Format, info};
use embassy_rp::gpio;
use embassy_sync::{
    blocking_mutex::raw::{CriticalSectionRawMutex, RawMutex},
    channel, signal,
};
use embassy_time::{Instant, Timer};
use fixed::{FixedI32, types::extra::U10};
use fixed_sqrt::FastSqrt;
use gcode::{Command, UCoord};

use crate::{
    CANCEL_WATCHERS, COMMAND_BUFFER_SIZE, CommandId, cancellation,
    driver::{self, HomeError, StepsPerSecond},
    status_leds::{self, Status},
    util::ArrayZipWith,
};

pub type ICoord = FixedI32<U10>;

#[derive(Debug, Clone, Copy, PartialEq, Eq, PartialOrd, Ord)]
pub struct MicronsPerStep(pub ICoord);

impl From<ICoord> for MicronsPerStep {
    fn from(value: ICoord) -> Self {
        Self(value)
    }
}

#[derive(Debug, Clone, Copy, PartialEq, Eq, PartialOrd, Ord)]
pub struct DegreesPerStep(pub ICoord);

impl From<ICoord> for DegreesPerStep {
    fn from(value: ICoord) -> Self {
        Self(value)
    }
}

#[derive(Debug, Clone, Copy, PartialEq, Eq)]
pub enum AxisUnit {
    Millimeters,
    Rotations,
}

#[derive(Debug, Clone, Copy, PartialEq, Eq)]
pub struct Axis {
    pub microns_per_step: MicronsPerStep,
    pub degrees_per_step: DegreesPerStep,
    pub unit: AxisUnit,
    pub length: ICoord,
}

fn diff(coord1: UCoord, coord2: UCoord) -> ICoord {
    if coord1 > coord2 {
        (coord1 - coord2).saturating_cast()
    } else {
        let abs_diff: ICoord = (coord2 - coord1).saturating_cast();
        abs_diff.saturating_neg()
    }
}

#[derive(Debug, Clone, Copy, PartialEq, Eq, PartialOrd, Ord)]
struct MillimetersPerSecond(pub UCoord);

impl Format for MillimetersPerSecond {
    fn format(&self, fmt: defmt::Formatter) {
        defmt::write!(fmt, "{}", Display2Format(&self.0))
    }
}

impl MillimetersPerSecond {
    fn to_steps_per_second(
        self,
        MicronsPerStep(microns_per_step): MicronsPerStep,
    ) -> StepsPerSecond {
        let microns = self.0 * UCoord::from_num(1000);
        let steps = microns / microns_per_step.unsigned_abs();
        StepsPerSecond(steps.saturating_cast())
    }
}

const DEFAULT_HOME_SPEED: MillimetersPerSecond = MillimetersPerSecond(UCoord::lit("120"));

const AXES: usize = 3;

pub struct State {
    is_homed: bool,
    /// Feedrate is always in terms of the C axis
    feedrate: MillimetersPerSecond,
    position: [UCoord; AXES],
    axes: [Axis; AXES],
    resume_button: gpio::Input<'static>,
    status_leds: &'static status_leds::Control,
    last_command_sent: Option<CommandId>,
}

impl State {
    pub fn new(
        axes: [Axis; AXES],
        status_leds: &'static status_leds::Control,
        resume_button: gpio::Input<'static>,
    ) -> Self {
        Self {
            is_homed: false,
            feedrate: MillimetersPerSecond(UCoord::lit("1")),
            position: [UCoord::ZERO; AXES],
            axes,
            resume_button,
            status_leds,
            last_command_sent: None,
        }
    }

    /// Returns whether we should wait for all previous commands to finish
    /// before executing this command or whether we can just go ahead and do it.
    /// For example,
    ///
    ///     G28 F20
    ///     G0  X50 Z50 F30
    ///     M18
    ///
    /// the first two commands can be run as soon as we get them, but the last
    /// (disable all steppers) has to wait for the first two to complete, lest
    /// we stop in the middle of a code!
    fn should_synchronize(command: &gcode::Command<{ AXES + 1 }>) -> bool {
        match command {
            gcode::Command::RapidMove(_)
            | gcode::Command::LinearMove(_)
            | gcode::Command::Home { .. }
            | gcode::Command::Stop
            | gcode::Command::ForceStop
            | gcode::Command::GetCurrentPosition => false,

            gcode::Command::Dwell(_)
            | gcode::Command::Park(_)
            | gcode::Command::EnableAllSteppers
            | gcode::Command::DisableAllSteppers
            | gcode::Command::Pause => true,
        }
    }
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

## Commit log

2025-11-09 Initial commit; http server on a pi pico w
2025-11-10 A (not working) attempt at parsing gcode over TCP
    [ast.rs, main.rs]
2025-11-10 Find the parser bug that caused it
    [parser.rs]
2025-11-11 Start of a driver for the A4988 stepper driver
    And drive it in bit-banging single-step mode from G0/G1. which is *not*
    fast enough, but it's fun!
2025-11-11 Offload stepper driver completely onto core1 (second core)
2025-11-15 Start rewriting stepper driver driver to use PIO
2025-11-16 in progress: Rewrite assembly for PIO
2025-11-16 Revert "in progress: Rewrite assembly for PIO"
    This reverts commit b5d91b30bbeca1747c91a7a74416293ed97fa92c.
    [main.rs]
2025-11-16 Beginning of a motion controller
    Tracks positions along all axes, can cause the X axis to zigzag (I
    watched it happen!) with the following program:
    G0 X4
    G0 X0
    G0 X4
    G0 X0
    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
2025-11-16 Draft two PIO programs (for motion and homing)
2025-11-17 Reapply "in progress: Rewrite assembly for PIO"
    This reverts commit 017e9827373559f067143c1b79700ef3e7609f5c.
2025-11-17 Full blown 3-axis motion controller, with sync
    This is starting to get real
    [main.rs, motion.rs]
2025-11-17 Document how exactly to plug the X axis in
2025-11-18 Parse M0 (stop) and M18 (disable steppers)
2025-11-18 Add enable all steppers command
2025-11-18 Implement disable / enable steppers via sleep pin
2025-11-18 Implement stop command, by clearing the queue of messages
    Ideally we'd also cancel the current command, but that's ~annoying so
    I'll do it later
2025-11-18 Kill home if we disable steppers
2025-11-18 Rename a4988 module to driver
    This is no longer just an a4988 driver, it's really just a general
    hardware driver module (and is about to become more so, with the
    addition of reading limit switches)
    [driver.rs, main.rs, motion.rs]
2025-11-18 Scratch homing routine
    This doesn't work, empirically - we had to pull the power to get it to
    not crash! But it's a start. Plus it's got some nice refactoring of the
    driver code.
    [driver.rs, main.rs, motion.rs]
2025-11-20 Set pins for homing the right way
2025-11-20 Homing routine cleanup
2025-11-22 Implement M114 "Get Current Position"
2025-11-22 if we're not changing an axis we don't want to move
    this was a funny bug
    [motion.rs]
2025-11-22 Turn C axis around
    "it's annoying to wire it the other way" she said
2025-11-22 Use fixed point math for C axis speed calculation
    Otherwise we lose all our precision, floor to zero, then panic with a
    divide by zero
    [motion.rs]
2025-11-22 a test of parsing with the c axis
    this worked (the client just had the wrong axis) but more tests is never
    bad.
    [parser.rs]
2025-11-22 Print which gcode command is invalid in the client
2025-11-22 defmt::Format on a thing
    I didn't commit what needed this, but it's also nice to have.
    [driver.rs]
2025-11-23 C axis coords are in rotations, not millimeters
    This is... annoying to get right, but makes the slicer way easier
2025-11-23 All STL files for parts
    [coil winder - belt tensioner.stl, coil winder - carriage.stl, coil winder - chuck.stl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]
2026-02-25 Rename probe-rs -> probe-rs-tools
2026-02-25 Add Pico W datasheet
2026-02-25 Pin nixpkgs
2026-02-25 Add parts for circuit board enclosure
    [circuit board enclosure - enclosure lid.stl, circuit board enclosure - enclosure.stl]
2026-02-25 Document axes and correct pins in source
    [main.rs]
2026-02-25 Use Performance power-save mode for wifi firmware
    Maybe this'll fix the flakes we've been seeing?
    [main.rs]
2026-02-28 document led pins
2026-02-28 Display status on LEDs based on initial wifi auth
2026-03-15 Refactor and generalize status LEDs
    Now we have a Status enum, which is the "domain specific" statuses, and
    maps to a per-color "Behavior", which can be either off, on, blinking
    slow, or blinking fast. There's an embassy task which runs the blinking
    behavior on a timer (though this is a little wrong, right now, since
    those timers are interrupted by new statuses being set).
    [main.rs]
2026-03-15 Expand an acronym in a comment
    old me knew what LSB meant. Present me *almost* forgot what it meant.
    Surely future me will have completely forgot, so let's actually explain
    what it means here to avoid knowledge-rot
    [driver.rs]
2026-03-15 Better timing for status LED blinking
    Get rid of the whole "either sleep or read from the signal" thing, and
    just poll the new status every 500ms. This is more reliable and simpler,
    and the extra load from always unconditionally polling is "fine", I'm
    told.
2026-03-15 Abort homing if we've gone too far
    Give the homing PIO program an extra "max_steps" input, which (if we
    blow past while trying to home) we see if we hit and error out if we
    did. Note that the PIO programs are basically maximum length now --- we
    were finally forced to use side-setting.
    [driver.rs, main.rs, motion.rs]
2026-03-15 Match specifically on () for homing errors
    [motion.rs]
2026-03-15 Add mDNS responder for coil-winder.local
    Adds mDNS support using edge-mdns so the device can be discovered at
    coil-winder.local on the local network. Key changes:
    - Add edge-mdns, edge-nal, edge-nal-embassy dependencies
    - Upgrade embassy-net to 0.8.0 with multicast support
    - Add mDNS responder task using edge-mdns
    - Register mDNS multicast MAC (01:00:5e:00:00:fb) with CYW43 hardware
    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
2026-03-15 Switch from static IP to DHCP
    Wait for DHCP to assign an IP address, then use that for mDNS
    advertisement. Increased StackResources from 3 to 4 to accommodate
    the DHCP socket alongside TCP server and UDP mDNS.
2026-03-15 client: Default to coil-winder.local instead of static IP
    Change the default address from 10.0.0.40:1234 to coil-winder.local:1234
    to use mDNS for discovery. Also change the addr argument type from
    SocketAddr to String to support hostnames.
2026-03-15 Add a separate LED status for "waiting for DHCP"
2026-03-22 Add pause button
2026-03-22 firmware,gcode: Implement "Pause" command
    Implement "Pause", a command that pauses the gcode program until the
    user presses the "resume" button. This'll be useful for things that
    require a human to do something before the program runs, like manually
    applying tension to the coil.
2026-03-22 slicer: Configurably pause before running program
    (but after the standard "enable steppers, home" preamble)
2026-03-22 Run clippy in CI (and fix all outstanding lints)
    [driver.rs, main.rs]
2026-03-22 firmware: Don't use wait_read_ready
    Sadly, the Right Thing To Do here doesn't work with embassy, because
    wait_read_ready doesn't ever return if the socket happens to be closed
    while it's waiting. It seems, actually, like there's literally nothing
    that can be done here (I guess we could timeout, but I'm resistant to
    that...). Instead, we need to just have circumstances where we can drop
    things like status responses on the floor. Sad!
2026-03-23 status-led: Blink faster
2026-04-19 driver: Reject motion command if not homed
    It is not a good idea to try to move when we don't know where we are.
2026-05-10 gcode: Use complete, not streaming, parsers
    Fixes a bug where the client would incorrectly think a `G28` command
    with no feedrate was invalid (because it returned Incomplete, since it
    thought it might still see a feedrate).
    [parser.rs]
2026-05-20 firmware: Run driver concurrently with motion
    The idea is that we can use this to do the math for the motion
    planning *concurrently* with the steps
    We'll see if this actuall pans out
2026-05-20 stall motion only when we have to
    this commit:
    - fixes a broken (?) IRQ wait in the driver (we should really be able to
    wait for the C-axis IRQ, but it never seems to fire --- i suspect
    since we only have two external IRQ lines from PIO)
    - adds pipeline stalls to the command queue, since some commands (e.g.,
    M18 / disable all steppers) require all previous commands to finish
    before they execute.
    [driver.rs, main.rs, motion.rs]
2026-05-20 reset the processor on gcode::Command::Stop (M0)
    this *definitely* stops everything but might not be the best way to do
    this. it's likely the simplest and possibly the most reliable, though.
    [main.rs]
2026-05-20 actually, use gcode::Command::EmergencyStop (M112)
    M0 should be a more elegant unconditional stop, which we'll have to
    figure out. being able to completely reset the machine could be useful,
    though.
    [ast.rs, motion.rs, parser.rs]
2026-05-20 implement M0 as a graceful stop
    cancel a bunch of tasks, clear out some fifos, de-initialize the PIO,
    halt all the state machines, and disable steppers, then wait for further
    instructions.
2026-05-20 correctly report commands when they finish
    - add a `report_done()` function to the driver, so that we can pass
    through a "done" status even if we don't do anything
    - only clear state machine FIFOs when we stop, so that we can pipeline
    homing and ordinary motion
    [driver.rs, motion.rs]
2026-05-20 fix old cancellation request hanging around in command loop
    [driver.rs]
2026-05-20 rename: "emergency stop" -> "force stop"
    rationale is: the term "emergency stop," legally, has hardware support
    requirements which we definitely do *not* implement here. RepRaps and
    Marlin use similar terminology ("full stop") for the same reason.
2026-05-20 fix hangup on zero-distance moves
    turns out i was wrong originally and you *can* wait on more than two
    IRQs from PIO! great!
    [driver.rs]
2026-05-20 gcode: Fix a clippy lint
    [parser.rs]
